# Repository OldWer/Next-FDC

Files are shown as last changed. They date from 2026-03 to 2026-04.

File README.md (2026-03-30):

# Next-FDC
A floppy drive controller for the ZX Spectrum Next (issues 1 and 2) based on the ZX Spectrum +3 FDC circuit. I have previously designed a version of this FDC that is compatible with the ZX Spectrum +2A and „turns it” into Spectrum +3, but it requires three signals (DRD, DRW, MTR) that are not present on the Next’s expansion bus (this applies to issues 1 and 2, issue 3 will have these signals on the bus). However, they can be fairly easily synthesized externally based on several data/address lines and that’s what I have done in this version.

<br/>The Next-FDC also works with regular ZX Spectrum +2A (and some clones, such as Sizif-512 and Harlequin 128), and I fully expect it to work with ZX Next issue 3 also (there just will be a little bit of redundancy, because in these cases the controller will create signals which are already being delivered by the computer itself).

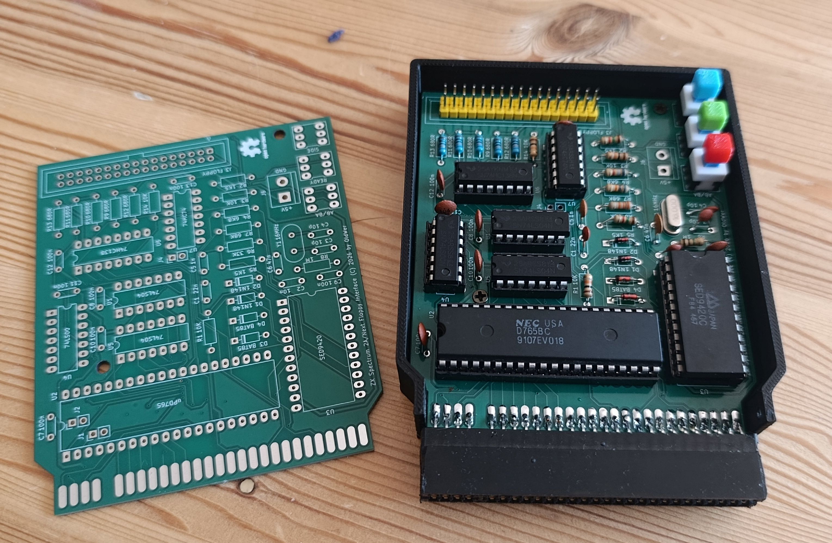
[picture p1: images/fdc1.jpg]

Please note that in order to actually use the floppy drive with the Next you have to switch the computer into +3/+3e personality, change some settings and also issue several OUT commands (see below).
## How to make it?
The build is pretty self-explanatory. The gerbers are in the _gerbers_ directory; I have used recommended JLCPCB settings. The Bill of Materials is available in the _bom_ directory and all the parts are described on the PCB. The case model is available in the _STL_ directory. Actual FDC chips (uPD765 and SED9420) are still available pretty cheaply on Aliexpress (and I never got a fake one when ordering).
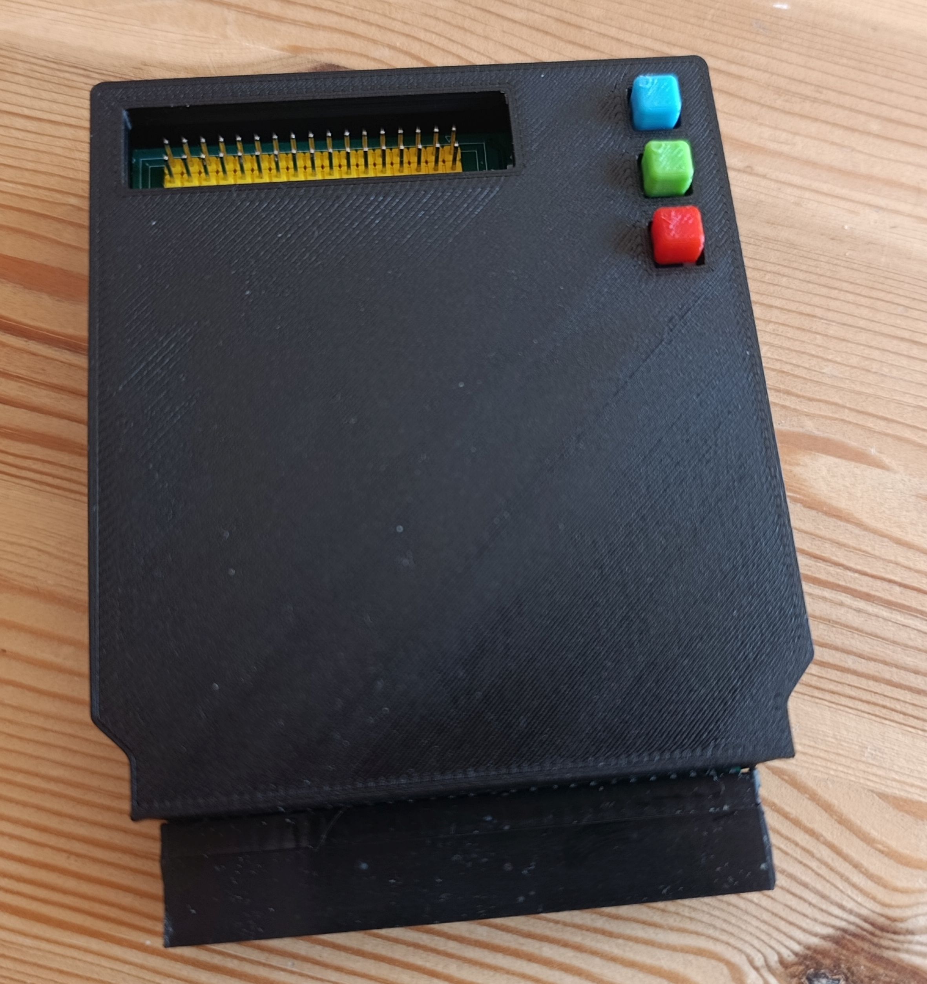
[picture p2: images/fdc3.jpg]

## How to use it?
In order to use the controller with the Next, you have to:
1. Switch the Next into +2A/+3 or +3e personality.
2. Press Space to go the configuration settings and disable DivmmcROM and DivmmcHW).
3. After reboot, go into +3 BASIC (or 48 BASIC).
4. Enter the following commands:
<br/>__OUT 9275, 136: OUT 9531, 223__
<br/>  _(Writing 223 to port 136 disables DACs that interfere with the FDC operation.)_
<br/>__OUT 9275, 138: OUT 9531, 8__
<br/>  _(Writing 8 to port 138 enables the port forwarding for port 1FFD to allow the I/O cycles to show up on the expansion bus.)_
<br/>__OUT 9275, 128: OUT 9531, 8__
<br/>  _(Writing 8 to port 128 enables the expansion bus.)_
5. Press Reset button.
6. Now go into BASIC again, enter the CAT command and see if it works!
I know that's pretty convoluted, but who knows, maybe Next developers can be talked into adding an appropriate option to the menu? ;-)
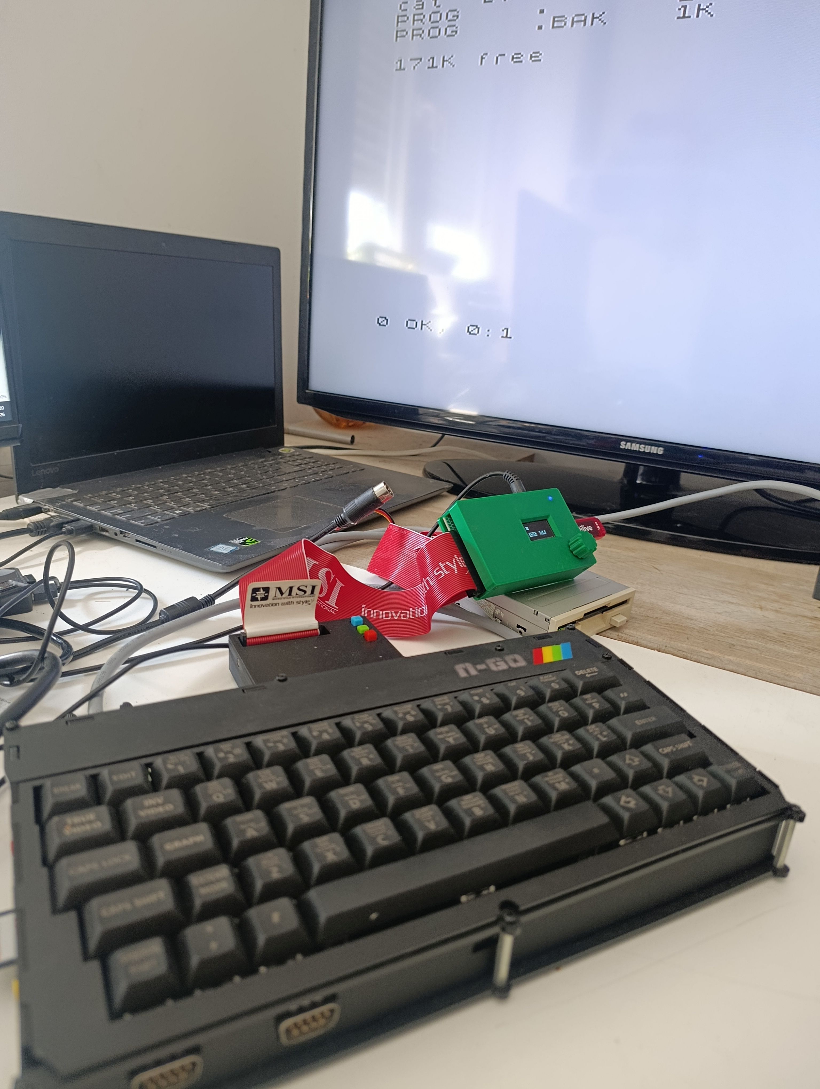
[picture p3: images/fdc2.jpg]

## Buttons
There are three buttons on the controller:
* The upper one (blue on the photo): switches disk side – you can e.g. format one side of a 3,5” floppy, then press this button and format/use the other side.
* The middle one (green): forces the READY signal when using IBM disk drives.
* The lower one (red): swaps drives A and B.

All these buttons can be used when the computer is switched on (obviously not in the middle of a disk operation).
## General remarks
* To use two IBM floppy drives, please use a floppy cable with the twist. To use a Gotek and an IBM drive, set the Gotek to DS1 and use a cable with the twist.
* Please note that to use HD floppies you have to cover the HD hole (e.g. with a piece of self-adhesive tape).
* Many thanks to Allen Albright and Tim Gilberts from the ZX Spectrum Next FB group, who had helped me with configuring the Next to support the FDC.
* If in doubt, contact me at oldwer@op.pl, I will be happy to help.

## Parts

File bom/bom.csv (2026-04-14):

Reference | Value | Datasheet | Footprint | Qty | DNP
C1 | 22nF | ~ | Capacitor_THT:C_Disc_D4.3mm_W1.9mm_P5.00mm | 1
C2 | 10nF | ~ | Capacitor_THT:C_Disc_D4.3mm_W1.9mm_P5.00mm | 1
C3,C4 | 10pF | ~ | Capacitor_THT:C_Disc_D4.3mm_W1.9mm_P5.00mm | 2
C5 | 1nF | ~ | Capacitor_THT:C_Disc_D4.3mm_W1.9mm_P5.00mm | 1
C6 | 47nF | ~ | Capacitor_THT:C_Disc_D4.3mm_W1.9mm_P5.00mm | 1
C7,C8,C9,C10,C11,C12,C13 | 100nF | ~ | Capacitor_THT:C_Disc_D4.3mm_W1.9mm_P5.00mm | 7
D1,D2 | 1N4148 | https://assets.nexperia.com/documents/data-sheet/1N4148_1N4448.pdf | Diode_THT:D_DO-35_SOD27_P7.62mm_Horizontal | 2
D3,D4 | BAT85 | ~ | Diode_THT:D_DO-35_SOD27_P7.62mm_Horizontal | 2
J1,J2,J4 | DRD_2A | ~ | Connector_PinHeader_2.54mm:PinHeader_1x02_P2.54mm_Vertical | 3
J3 | Floppy | ~ | Connector_IDC:IDC-Header_2x17_P2.54mm_Vertical | 1
J6 | Power | ~ | TerminalBlock:TerminalBlock_bornier-2_P5.08mm | 1
R1,R3,R14 | 10K | ~ | Resistor_THT:R_Axial_DIN0207_L6.3mm_D2.5mm_P10.16mm_Horizontal | 3
R2,R5 | 1K5 | ~ | Resistor_THT:R_Axial_DIN0207_L6.3mm_D2.5mm_P10.16mm_Horizontal | 2
R4 | 6K8 | ~ | Resistor_THT:R_Axial_DIN0207_L6.3mm_D2.5mm_P10.16mm_Horizontal | 1
R6 | 33K | ~ | Resistor_THT:R_Axial_DIN0207_L6.3mm_D2.5mm_P10.16mm_Horizontal | 1
R7 | 68K | ~ | Resistor_THT:R_Axial_DIN0207_L6.3mm_D2.5mm_P10.16mm_Horizontal | 1
R8 | 1M | ~ | Resistor_THT:R_Axial_DIN0207_L6.3mm_D2.5mm_P10.16mm_Horizontal | 1
R9,R10,R11,R12,R13 | 680R | ~ | Resistor_THT:R_Axial_DIN0207_L6.3mm_D2.5mm_P10.16mm_Horizontal | 5
SW1 | AB/BA |  | SW_DPDT_XLX, 8x8 mm switch | 1
SW2 | SIDE |  | SW_DPDT_XLX, 8x8 mm switch | 1
SW3 | READY |  | SW_DPDT_XLX, 8x8 mm switch | 1
U1,U5 | 74LS04 | http://www.ti.com/lit/gpn/sn74LS04 | Package_DIP:DIP-14_W7.62mm_LongPads | 2
U2 | UPD765 |  | Package_DIP:DIP-40_W15.24mm_LongPads | 1
U3 | SED9420 |  | Package_DIP:DIP-24_W15.24mm_LongPads | 1
U4 | 74LS00 | http://www.ti.com/lit/gpn/sn74ls00 | Package_DIP:DIP-14_W7.62mm_LongPads | 1
U6 | 74HC138 | http://www.ti.com/lit/ds/symlink/cd74hc238.pdf | Package_DIP:DIP-16_W7.62mm_LongPads | 1
U7 | 74HC74 | 74xx/74hc_hct74.pdf | Package_DIP:DIP-14_W7.62mm_LongPads | 1
Y1 | 16MHz | ~ | Crystal:Crystal_HC49-U_Vertical | 1
Z1 | ZXBUS+2A/3` |  | Common:ZX_CONN | 1

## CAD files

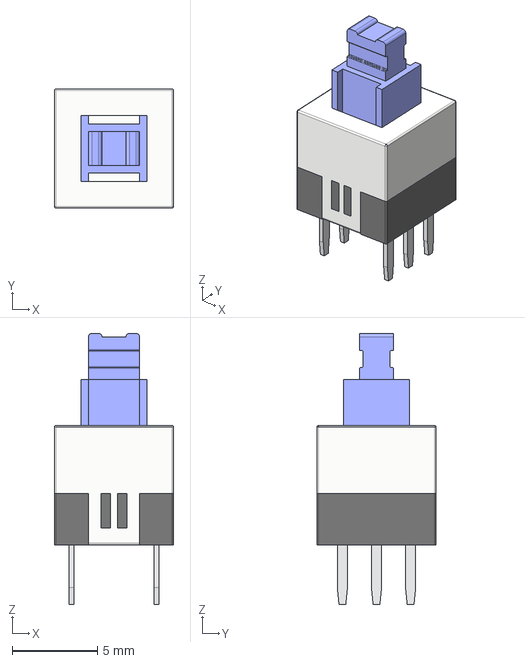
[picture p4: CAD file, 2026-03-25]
Models/6pin.step
7.00 x 7.00 x 15.9 mm

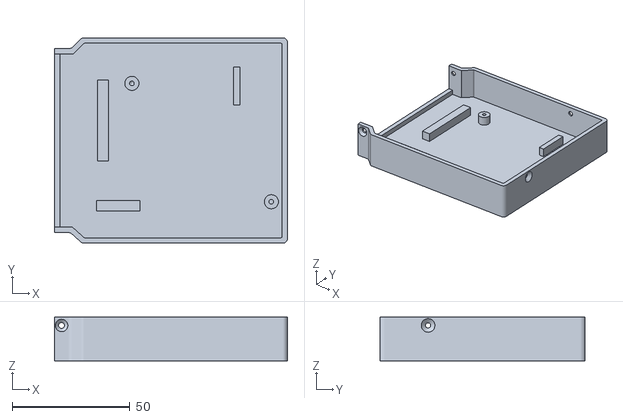
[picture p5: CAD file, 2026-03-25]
STL/fdc_bot.stl
98.9 x 87.2 x 18.5

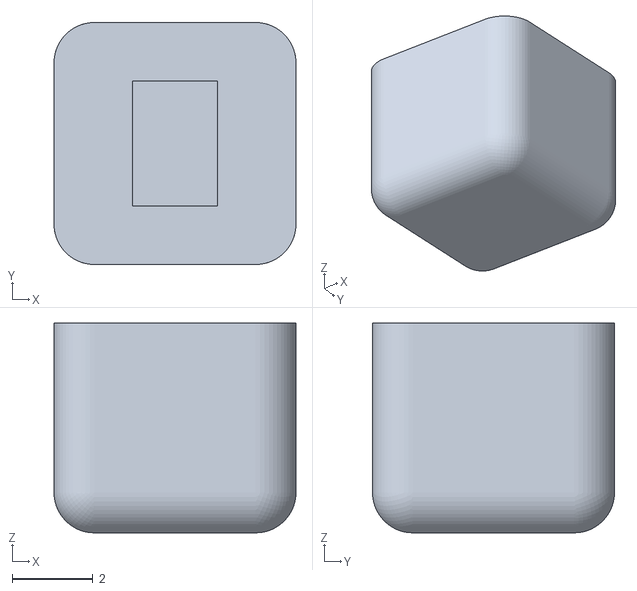
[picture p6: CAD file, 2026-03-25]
STL/fdc_btn.stl
6.00 x 6.00 x 5.20

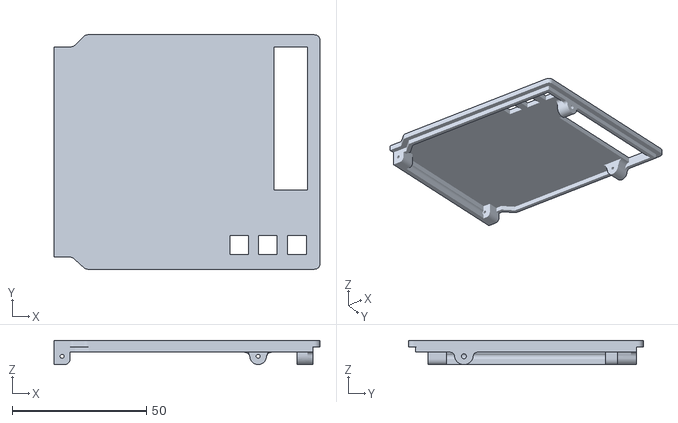
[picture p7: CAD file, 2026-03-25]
STL/fdc_top.stl
98.9 x 87.2 x 9.00

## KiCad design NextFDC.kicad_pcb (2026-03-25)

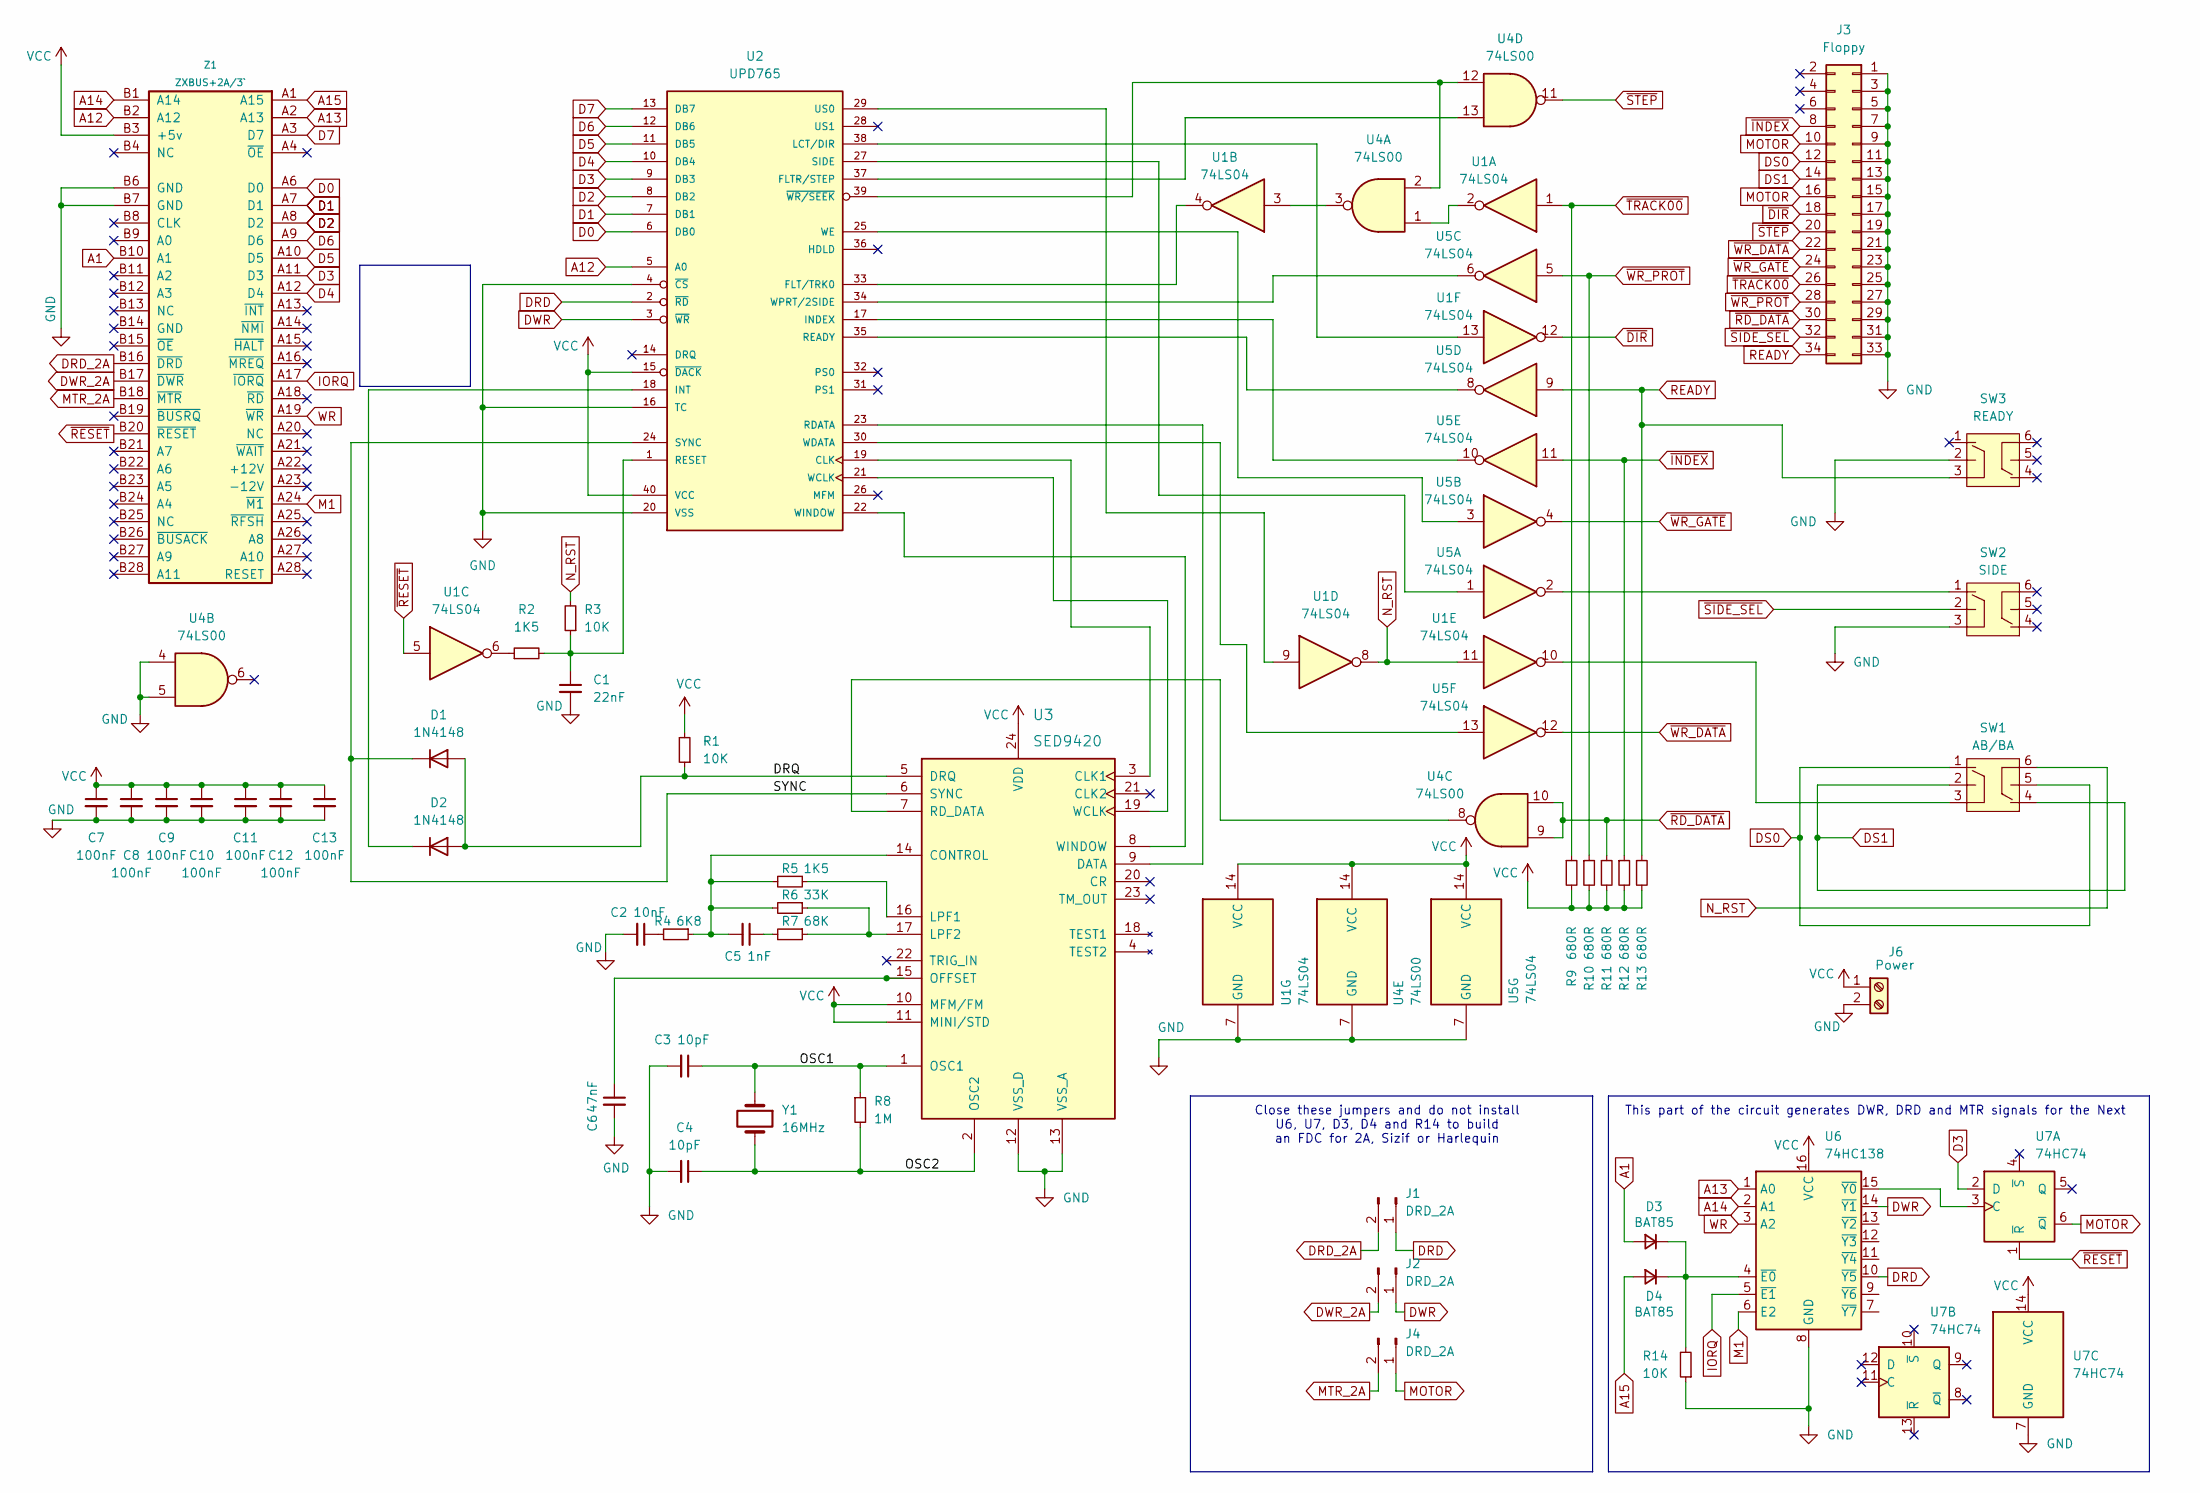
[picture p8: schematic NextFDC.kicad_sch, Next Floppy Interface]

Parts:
C1: 22nF; C_Disc_D4.3mm_W1.9mm_P5.00mm
C2: 10nF; C_Disc_D4.3mm_W1.9mm_P5.00mm
C3, C4: 10pF; C_Disc_D4.3mm_W1.9mm_P5.00mm
C5: 1nF; C_Disc_D4.3mm_W1.9mm_P5.00mm
C6: 47nF; C_Disc_D4.3mm_W1.9mm_P5.00mm
C7, C8, C9, C10, C11, C12, C13: 100nF; C_Disc_D4.3mm_W1.9mm_P5.00mm
D1, D2: 1N4148; D_DO-35_SOD27_P7.62mm_Horizontal
D3, D4: BAT85; D_DO-35_SOD27_P7.62mm_Horizontal
J1, J2, J4: DRD_2A; PinHeader_1x02_P2.54mm_Vertical
J3: Floppy; IDC-Header_2x17_P2.54mm_Vertical
J6: Power; TerminalBlock_bornier-2_P5.08mm
R1, R3, R14: 10K; R_Axial_DIN0207_L6.3mm_D2.5mm_P10.16mm_Horizontal
R2, R5: 1K5; R_Axial_DIN0207_L6.3mm_D2.5mm_P10.16mm_Horizontal
R4: 6K8; R_Axial_DIN0207_L6.3mm_D2.5mm_P10.16mm_Horizontal
R6: 33K; R_Axial_DIN0207_L6.3mm_D2.5mm_P10.16mm_Horizontal
R7: 68K; R_Axial_DIN0207_L6.3mm_D2.5mm_P10.16mm_Horizontal
R8: 1M; R_Axial_DIN0207_L6.3mm_D2.5mm_P10.16mm_Horizontal
R9, R10, R11, R12, R13: 680R; R_Axial_DIN0207_L6.3mm_D2.5mm_P10.16mm_Horizontal
SW1: AB/BA; SW_DPDT_XLX
SW2: SIDE; SW_DPDT_XLX
SW3: READY; SW_DPDT_XLX
U1, U5: 74LS04; DIP-14_W7.62mm_LongPads
U2: UPD765; DIP-40_W15.24mm_LongPads
U3: SED9420; DIP-24_W15.24mm_LongPads
U4: 74LS00; DIP-14_W7.62mm_LongPads
U6: 74HC138; DIP-16_W7.62mm_LongPads
U7: 74HC74; DIP-14_W7.62mm_LongPads
Y1: 16MHz; Crystal_HC49-U_Vertical
Z1: ZXBUS+2A/3`; ZX_CONN

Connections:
/DRQ: D1.2 (A), D2.2 (A), R1.1, U3.5 (DRQ)
/OSC1: C3.1, R8.1, U3.1 (OSC1), Y1.1
/OSC2: C4.1, R8.2, U3.2 (OSC2), Y1.2
/SYNC: D1.1 (K), U2.24 (SYNC), U3.6 (SYNC)
A1: D3.2 (A), Z1.B10 (A1)
A12: U2.5 (A0), Z1.B2 (A12)
A13: U6.1 (A0), Z1.A2 (A13)
A14: U6.2 (A1), Z1.B1 (A14)
A15: D4.2 (A), Z1.A1 (A15)
D0: U2.6 (DB0), Z1.A6 (D0)
D1: U2.7 (DB1), Z1.A7 (D1)
D2: U2.8 (DB2), Z1.A8 (D2)
D3: U2.9 (DB3), U7.2 (D), Z1.A11 (D3)
D4: U2.10 (DB4), Z1.A12 (D4)
D5: U2.11 (DB5), Z1.A10 (D5)
D6: U2.12 (DB6), Z1.A9 (D6)
D7: U2.13 (DB7), Z1.A3 (D7)
DRD: J1.1, U2.2 (~RD), U6.10 (~Y5)
DRD_2A: J1.2, Z1.B16 (~DRD)
DS0: J3.12, SW1.1, SW1.5
DS1: J3.14, SW1.2, SW1.4
DWR: J2.1, U2.3 (~WR), U6.14 (~Y1)
DWR_2A: J2.2, Z1.B17 (~DWR)
GND: C1.2, C2.2, C3.2, C4.2, C6.2, C7.2, C8.2, C9.2, C10.2, C11.2, C12.2, C13.2, J3.1, J3.3, J3.5, J3.7, J3.9, J3.11, J3.13, J3.15, J3.17, J3.19, J3.21, J3.23, J3.25, J3.27, J3.29, J3.31, J3.33, J6.2, R14.1, SW2.3, SW3.2, U1.7 (GND), U2.4 (~CS), U2.16 (TC), U2.20 (VSS), U3.12 (VSS_D), U3.13 (VSS_A), U4.4, U4.5, U4.7 (GND), U5.7 (GND), U6.8 (GND), U7.7 (GND), Z1.B6 (GND), Z1.B7 (GND)
IORQ: U6.5 (~E1), Z1.A17 (~IORQ)
M1: U6.6 (E2), Z1.A24 (~M1)
MOTOR: J3.10, J3.16, J4.1, U7.6 (~Q)
MTR_2A: J4.2, Z1.B18 (~MTR)
N_RST: R3.2, SW1.6, U1.8, U1.11
unnamed: C2.1, R4.2
unnamed: C5.1, R7.2
unnamed: D2.1 (K), U2.18 (INT)
unnamed: D3.1 (K), D4.1 (K), R14.2, U6.4 (~E0)
unnamed: R2.1, U1.6
unnamed: SW1.3, U1.10
unnamed: SW2.1, U5.2
unnamed: U1.2, U4.1
unnamed: U1.3, U4.3
unnamed: U2.19 (CLK), U3.3 (CLK1)
unnamed: U2.37 (FLTR/STEP), U4.13
unnamed: U1.4, U2.33 (FLT/TRK0)
unnamed: U2.17 (INDEX), U5.10
unnamed: U1.13, U2.38 (LCT/DIR)
unnamed: U2.23 (RDATA), U3.9 (DATA)
unnamed: U2.35 (READY), U5.8
unnamed: C1.1, R2.2, R3.1, U2.1 (RESET)
unnamed: U2.27 (SIDE), U5.1
unnamed: U1.9, U2.29 (US0)
unnamed: U2.21 (WCLK), U3.19 (WCLK)
unnamed: U2.30 (WDATA), U5.13
unnamed: U2.25 (WE), U5.3
unnamed: U2.22 (WINDOW), U3.8 (WINDOW)
unnamed: U2.34 (WPRT/2SIDE), U5.6
unnamed: U2.39 (~WR/SEEK), U4.2, U4.12
unnamed: C5.2, R4.1, R5.2, R6.2, U3.14 (CONTROL)
unnamed: R5.1, U3.16 (LPF1)
unnamed: R6.1, R7.1, U3.17 (LPF2)
unnamed: C6.1, U3.15 (OFFSET)
unnamed: U3.7 (RD_DATA), U4.8
unnamed: U6.15 (~Y0), U7.3 (C)
READY: J3.34, R13.1, SW3.3, U5.9
VCC: C7.1, C8.1, C9.1, C10.1, C11.1, C12.1, C13.1, J6.1, R1.2, R9.2, R10.2, R11.2, R12.2, R13.2, U1.14 (VCC), U2.15 (~DACK), U2.40 (VCC), U3.10 (MFM/FM), U3.11 (MINI/STD), U3.24 (VDD), U4.14 (VCC), U5.14 (VCC), U6.16 (VCC), U7.14 (VCC), Z1.B3 (+5v)
WR: U6.3 (A2), Z1.A19 (~WR)
~DIR: J3.18, U1.12
~INDEX: J3.8, R12.1, U5.11
~RD_DATA: J3.30, R11.1, U4.9, U4.10
~RESET: U1.5, U7.1 (~R), Z1.B20 (~RESET)
~SIDE_SEL: J3.32, SW2.2
~STEP: J3.20, U4.11
~TRACK00: J3.26, R9.1, U1.1
~WR_DATA: J3.22, U5.12
~WR_GATE: J3.24, U5.4
~WR_PROT: J3.28, R10.1, U5.5

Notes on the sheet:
This part of the circuit generates DWR, DRD and MTR signals for the Next
Close these jumpers and do not install U6, U7, D3, D4 and R14 to build an FDC for 2A, Sizif or Harlequin

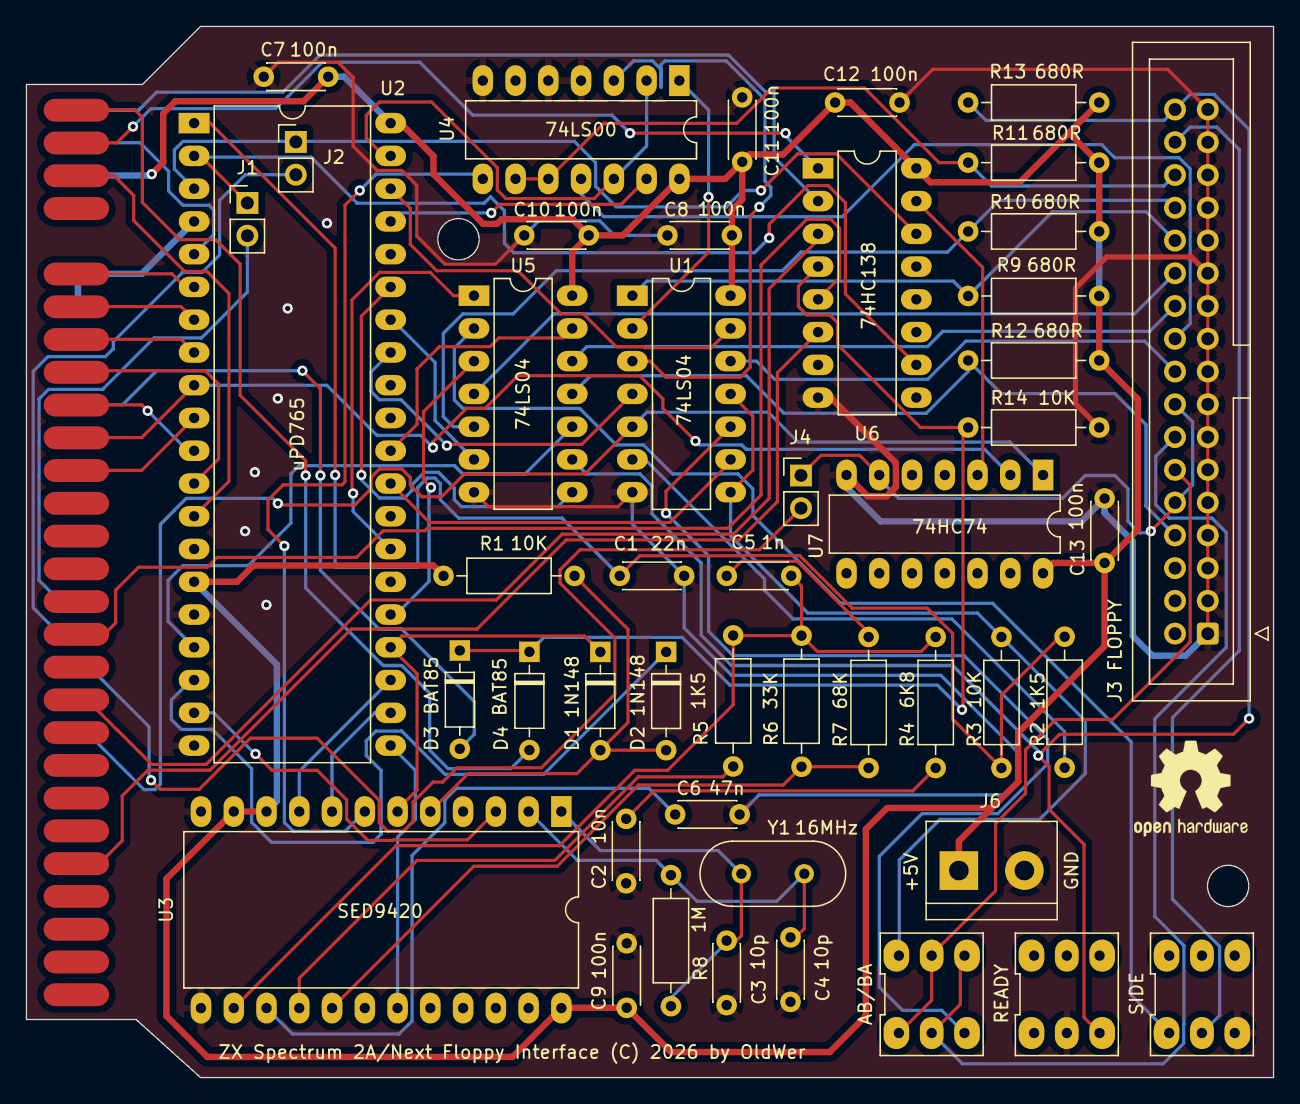
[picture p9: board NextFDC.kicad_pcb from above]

Board: 2 copper layers, 96.7 x 81.5 mm, 48 parts (1 on the bottom side), 73 nets.

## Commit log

2026-03-30 Enhance README with usage and build instructions
    Expanded the README to include detailed usage instructions, build information, and button functionalities for the floppy drive controller.
2026-03-30 Add gerber files information to README
2026-03-30 Update README to clarify button functionality
2026-04-14 Modify switch entries in bom.csv with size details
    Updated switch descriptions to include size information.
    [bom.csv]

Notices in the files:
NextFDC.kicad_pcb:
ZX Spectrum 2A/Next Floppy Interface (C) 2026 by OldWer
